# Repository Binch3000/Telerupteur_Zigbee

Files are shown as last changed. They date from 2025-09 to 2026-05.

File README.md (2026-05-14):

# Telerupteur ZigBee FR
Carte de commande pour le contrôle d'un télérupteur avec retour d'état de l'éclairage.

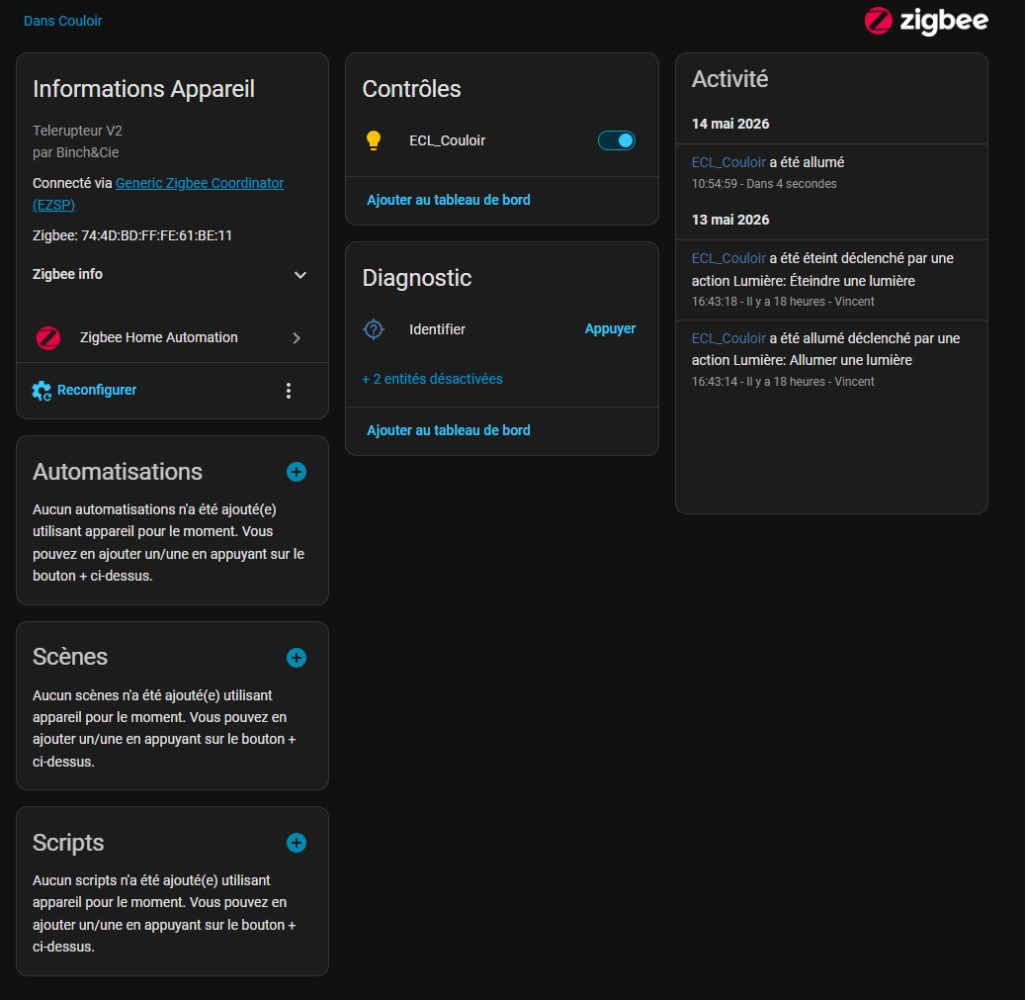
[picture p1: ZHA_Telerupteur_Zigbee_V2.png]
Image ZHA

  
## Pourquoi
Le télérupteur Legrand Drivia 1.991.21 ne remplis pas mon cahier des charges.
J'ai un bon vieux télérupteur à bobine, avec lequel il est possible d'avoir des témoins visuels sur chaque bouton-poussoir. (LED)
L'autre avantage, c'est qu'il se monte comme un bouton-poussoir à l'emplacement voulu.
Il faut également récupérer une alimentation (la même que le télérupteur) ainsi que la puissance de l'éclairage.  

## Liste des composants

Détail dans le ficier ibom.html
- [µP ESP32H2 SuperMini (x1)](https://fr.aliexpress.com/item/1005007235112528.html)
- [Relais HF49FD (x1) HF49FD-005-1H11](https://fr.aliexpress.com/item/1005005163929430.html)

Pour le moment le circuit est maintenu chez moi avec cette boite, dans une GTL. Prendre la version 50-100mm suffit. https://fr.aliexpress.com/item/32624897936.html

## Schéma
- Câblage
- Installation perso

## Évolution :
En fonction des demandes, il sera possible de continuer à développer le projet.
Ceci n'est que quelques idées que j'avais en tête.

- Création d'une boite à imprimer en 3D
- Mise à jour par OTA

## Divers
J'ai la possibilité d'expédier une carte vierge ou même prêt à l'utilisation selon vos besoins.

# ZigBee Remote Switch EN
Control board for controlling a remote switch with lighting status feedback.

Image ZHA

## Why
The Legrand Drivia 1.991.21 remote switch doesn't meet my requirements.
I have a good old-fashioned coil-type remote switch, which allows for visual indicators on each push button (LEDs).
Another advantage is that it can be mounted like a push button in the desired location.
It also requires a power supply (the same as the remote switch) and the power supply for the lighting.

## Component List

Details in the ibom.html file
- [µP ESP32H2 SuperMini (x1)](https://fr.aliexpress.com/item/1005007235112528.html)
- [HF49FD Relay (x1) HF49FD-005-1H11](https://fr.aliexpress.com/item/1005005163929430.html)

For now, the circuit is maintained at home with this box, in a GTL. The 50-100mm version is sufficient. https://fr.aliexpress.com/item/32624897936.html

## Diagram
- Wiring
- Custom Installation

## Evolution:
Depending on demand, it will be possible to continue developing the project.
These are just a few ideas I had in mind.

- Creation of a 3D printed box
- OTA updates

## Miscellaneous
I can ship a blank card or even a ready-to-use one, depending on your needs.

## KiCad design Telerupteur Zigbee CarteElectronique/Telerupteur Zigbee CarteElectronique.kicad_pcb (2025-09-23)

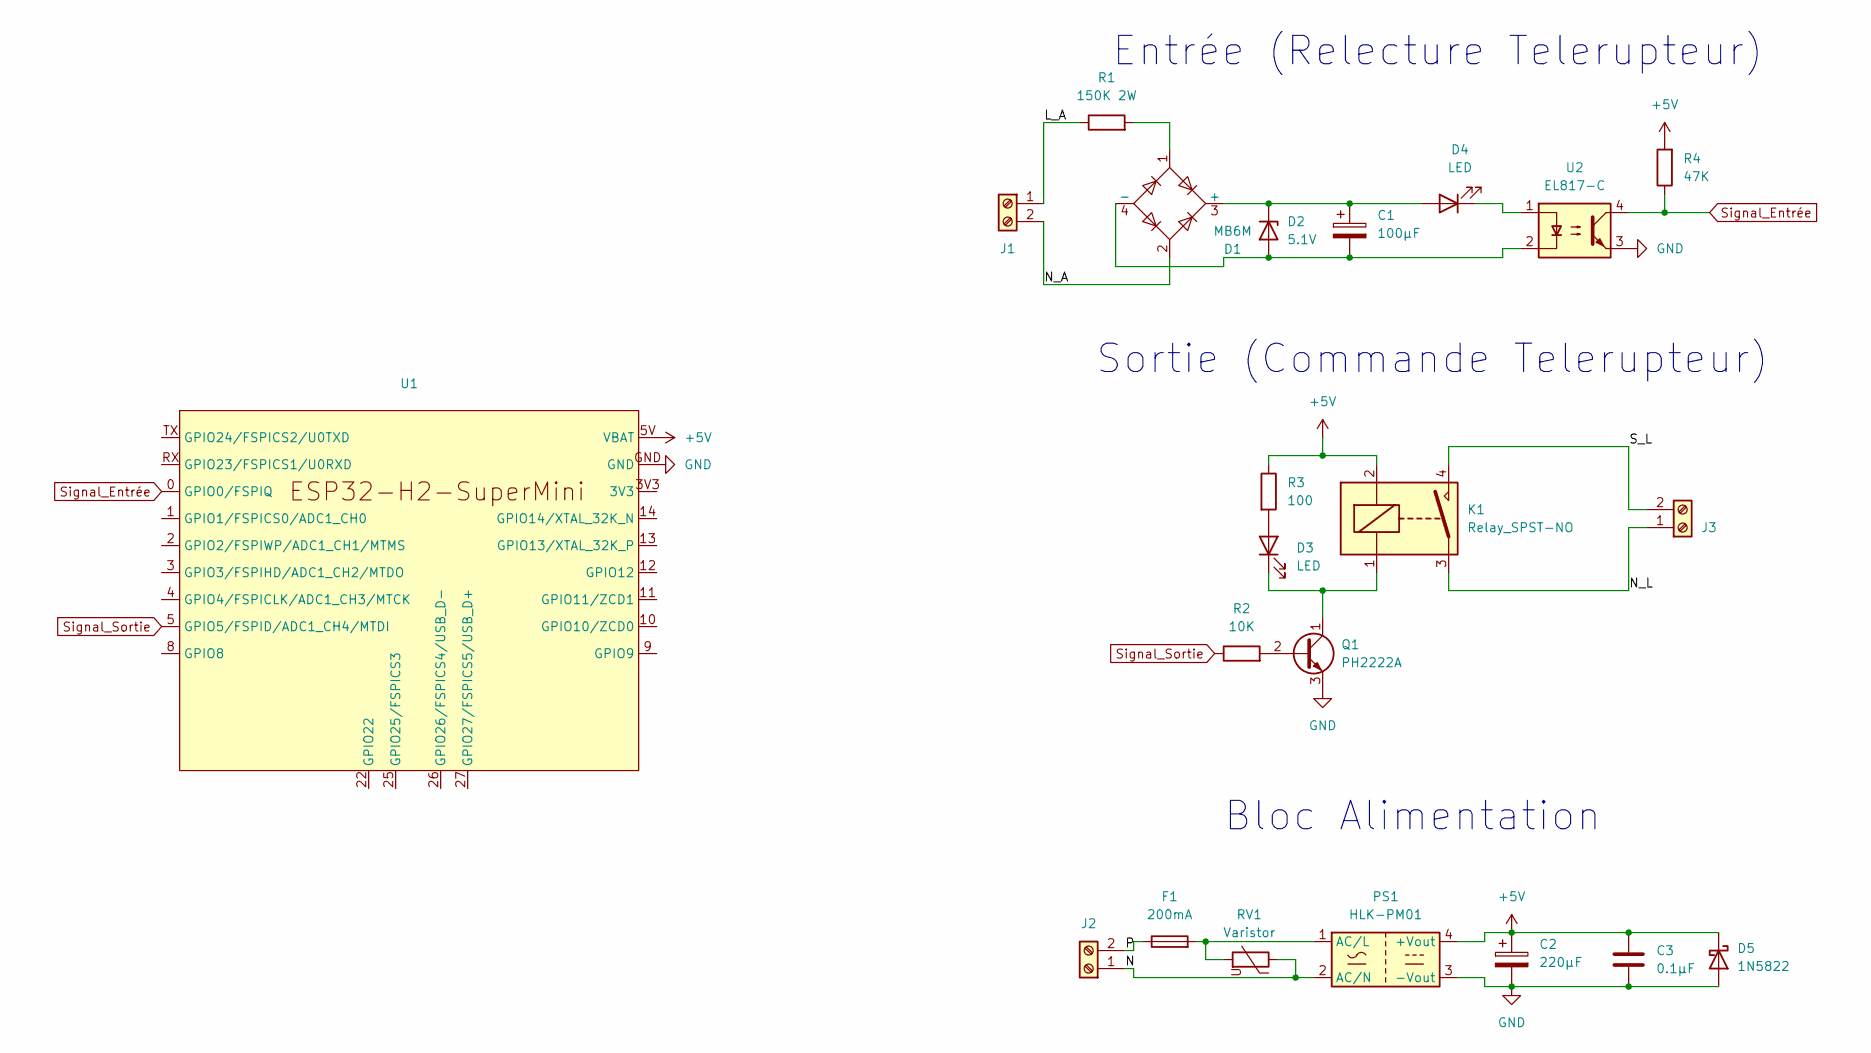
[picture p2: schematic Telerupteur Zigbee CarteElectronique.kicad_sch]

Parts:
C1: 100µF; CP_Radial_D6.3mm_P2.50mm
C2: 220µF; CP_Radial_D6.3mm_P2.50mm
C3: 0.1µF; C_Rect_L10.3mm_W5.0mm_P7.50mm_MKS4
D1: MB6M; Diode_Bridge_DIP-4_W5.08mm_P2.54mm
D2: 5.1V; D_A-405_P7.62mm_Horizontal
D3, D4: LED; LED_D3.0mm
D5: 1N5822; D_T-1_P10.16mm_Horizontal
F1: 200mA; Fuseholder_Cylinder-5x20mm_Schurter_FAB_0031-355x_Horizonta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
J1, J2, J3: Screw_Terminal_01x02; TerminalBlock_Phoenix_PT-1,5-2-5.0-H_1x02_P5.00mm_Horizontal
K1: Relay_SPST-NO; HF49FD
PS1: HLK-PM01; Converter_ACDC_Hi-Link_HLK-PMxx
Q1: PH2222A; TO-92L_Inline_Wide
R1: 150K 2W; R_Axial_DIN0516_L15.5mm_D5.0mm_P20.32mm_Horizontal
R2: 10K; R_Axial_DIN0207_L6.3mm_D2.5mm_P10.16mm_Horizontal
R3: 100; R_Axial_DIN0207_L6.3mm_D2.5mm_P10.16mm_Horizontal
R4: 47K; R_Axial_DIN0207_L6.3mm_D2.5mm_P10.16mm_Horizontal
RV1: Varistor; RV_Disc_D12mm_W3.9mm_P7.5mm
U1: ESP32-H2-SuperMini
U2: EL817-C; DIP-4_W7.62mm

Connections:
+5V: C2.1, C3.1, D5.1 (K), K1.2, PS1.4 (+Vout), R3.1, R4.2, U1.5V (VBAT)
/L_A: J1.1, R1.1
/N: J2.1, PS1.2 (AC/N), RV1.1
/N_A: D1.2, J1.2
/N_L: J3.1, K1.3
/P: F1.1, J2.2
/S_L: J3.2, K1.4
GND: C2.2, C3.2, D5.2 (A), PS1.3 (-Vout), Q1.3 (E), U1.GND, U2.3
unnamed: C1.1, D1.3 (+), D2.1 (K), D4.2 (A)
unnamed: C1.2, D1.4 (-), D2.2 (A), U2.2
unnamed: D1.1, R1.2
unnamed: D3.2 (A), R3.2
unnamed: D3.1 (K), K1.1, Q1.1 (C)
unnamed: D4.1 (K), U2.1
unnamed: F1.2, PS1.1 (AC/L), RV1.2
unnamed: Q1.2 (B), R2.2
Signal_Entrée: R4.1, U1.0 (GPIO0/FSPIQ), U2.4
Signal_Sortie: R2.1, U1.5 (GPIO5/FSPID/ADC1_CH4/MTDI)

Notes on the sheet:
Bloc Alimentation
Entrée (Relecture Telerupteur)
Sortie (Commande Telerupteur)

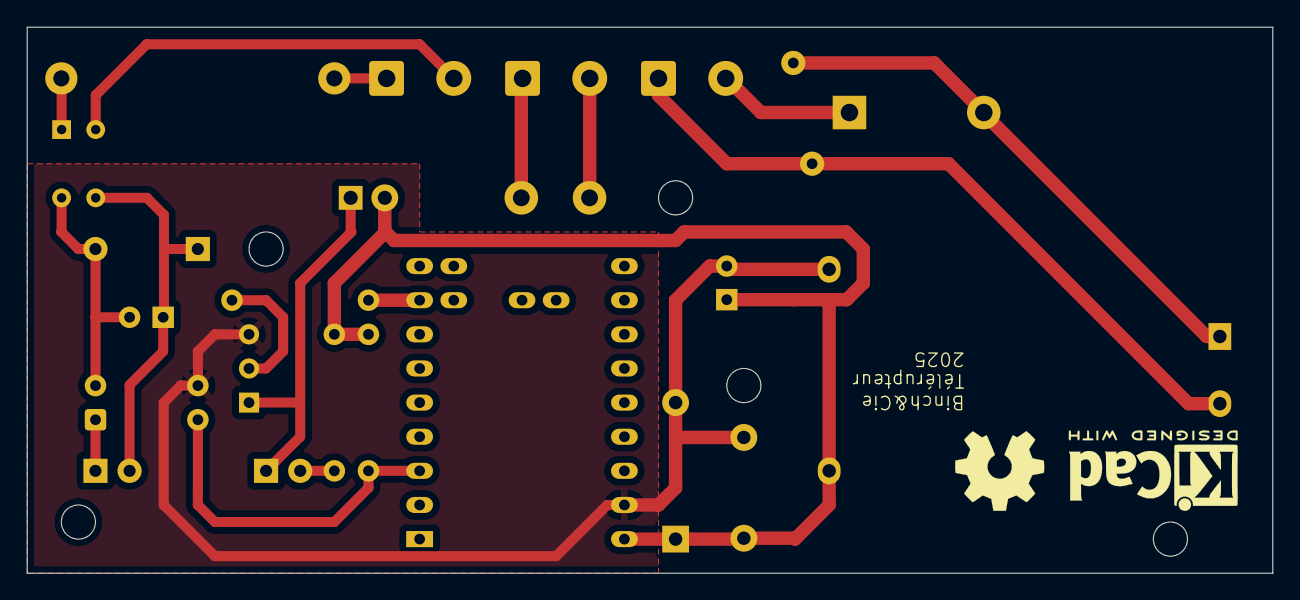
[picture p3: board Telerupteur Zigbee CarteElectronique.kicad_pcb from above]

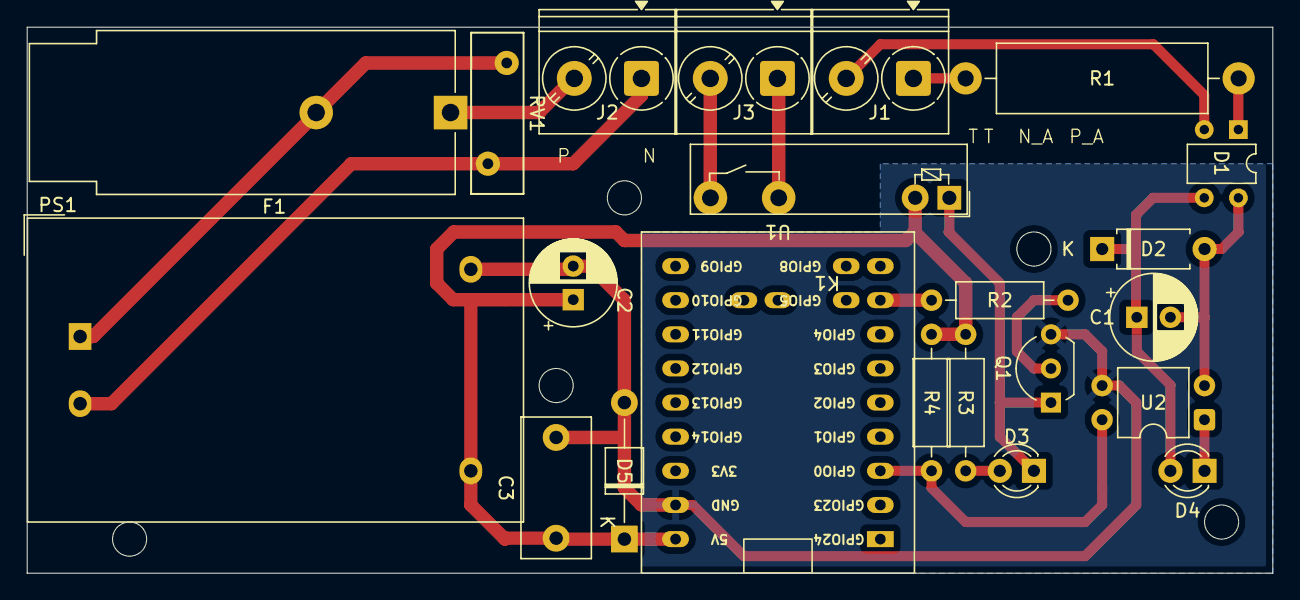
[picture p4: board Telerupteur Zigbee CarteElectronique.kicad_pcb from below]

Board: 2 copper layers, 92.7 x 40.6 mm, 22 parts (22 on the bottom side), 18 nets.

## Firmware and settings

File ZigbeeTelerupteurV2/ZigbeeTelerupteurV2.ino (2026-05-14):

#ifndef ZIGBEE_MODE_ZCZR
#error "Zigbee end device mode is not selected in Tools->Zigbee mode"
#endif

#include "esp_zigbee_core.h"
#include "freertos/FreeRTOS.h"
#include "freertos/task.h"
#include "ha/esp_zigbee_ha_standard.h"

//Attribution des END_POINT Configuration ZigBee
#define END_POINT_1 0x01

//--------Sortie ----------//
//Attribution des pin de sortie
static const byte pinSortie1 = 5;
static const byte pinIdentify = 13;

//Tableau des Pin de sorties
#define NB_PIN_OUT 2
const uint8_t PIN_OUT[NB_PIN_OUT] = { pinSortie1, pinIdentify };            //Attribution des PINs de sorties
const uint8_t END_POINT_OUT_ID[NB_PIN_OUT] = { END_POINT_1, END_POINT_1 };  //Attribution des END_POINT en fonction des PIN_OUT
bool ETAT_LED_OUT[NB_PIN_OUT];


//-------- Entrée ----------//
//Attribution des pin d'entrée
static const byte pinEntre1 = 0;


//Tableau des Pin de entrées
#define NB_PIN_IN 1
const uint8_t PIN_IN[NB_PIN_IN] = { pinEntre1 };             //Attribution des PINs de entrées
const uint8_t END_POINT_IN_ID[NB_PIN_IN] = { END_POINT_1 };  //Attribution des END_POINT en fonction des PIN_INT
bool ETAT_LED_IN[NB_PIN_IN];
bool VAL_COUR_IN = false;  //Valeur Courante Entrante

#define ESP_ZB_ZR_CONFIG() \
  { \
    .esp_zb_role = ESP_ZB_DEVICE_TYPE_ROUTER, \
    .install_code_policy = INSTALLCODE_POLICY_ENABLE, \
    .nwk_cfg = { \
      .zczr_cfg = { \
        .max_children = MAX_CHILDREN, \
      }, \
    }, \
  }

#define ESP_ZB_DEFAULT_RADIO_CONFIG() \
  { .radio_mode = ZB_RADIO_MODE_NATIVE, }

#define ESP_ZB_DEFAULT_HOST_CONFIG() \
  { .host_connection_mode = ZB_HOST_CONNECTION_MODE_NONE, }

/* Zigbee configuration */
#define MAX_CHILDREN 10                                                  /* the max amount of connected devices */
#define INSTALLCODE_POLICY_ENABLE false                                  /* enable the install code policy for security */
#define ESP_ZB_PRIMARY_CHANNEL_MASK ESP_ZB_TRANSCEIVER_ALL_CHANNELS_MASK /* Zigbee primary channel mask use in the example */

/********************* Zigbee functions **************************/

static void Entree_Binaire() {
  for (uint8_t IN = 0; IN < NB_PIN_IN; IN++) {
    // Lire l'état de la broche
    VAL_COUR_IN = !digitalRead(PIN_IN[IN]);  //Lecture etat pin inversée
    // Si l'état a changé
    if (VAL_COUR_IN != ETAT_LED_IN[IN]) {
      ETAT_LED_IN[IN] = VAL_COUR_IN;  // Mettre à jour l'état local
      // Afficher le changement d'état
      if (VAL_COUR_IN) {
        Serial.print("Activation pin : ");
      } else {
        Serial.print("Désactivation pin : ");
      }
      Serial.println(PIN_IN[IN]);
      // Vérification explicite des endpoints
      esp_err_t err = ESP_OK;  // Initialiser la variable d'erreur
      log_v("Updating on/off light state to %u", VAL_COUR_IN);
      /* Update on/off light state */
      esp_zb_lock_acquire(portMAX_DELAY);
      err = esp_zb_zcl_set_attribute_val(END_POINT_IN_ID[IN], ESP_ZB_ZCL_CLUSTER_ID_ON_OFF, ESP_ZB_ZCL_CLUSTER_SERVER_ROLE, ESP_ZB_ZCL_ATTR_ON_OFF_ON_OFF_ID, &VAL_COUR_IN, false);
      esp_zb_lock_release();

      // Vérifier le résultat de l'opération
      if (err != ESP_OK) {
        printf("Erreur lors de l'envoi de la commande pour EndPoint %d : %d\n", END_POINT_IN_ID[IN], err);
      } else {
        printf("Commande envoyée avec succès pour EndPoint %d.\n", END_POINT_IN_ID[IN]);
      }
    }
  }
}

static void bdb_start_top_level_commissioning_cb(uint8_t mode_mask) {
  ESP_ERROR_CHECK(esp_zb_bdb_start_top_level_commissioning(mode_mask));
}

void esp_zb_app_signal_handler(esp_zb_app_signal_t *signal_struct) {
  uint32_t *p_sg_p = signal_struct->p_app_signal;
  esp_err_t err_status = signal_struct->esp_err_status;
  esp_zb_app_signal_type_t sig_type = (esp_zb_app_signal_type_t)*p_sg_p;
  switch (sig_type) {
    case ESP_ZB_ZDO_SIGNAL_SKIP_STARTUP:
      log_i("Zigbee stack initialized");
      esp_zb_bdb_start_top_level_commissioning(ESP_ZB_BDB_MODE_INITIALIZATION);
      break;
    case ESP_ZB_BDB_SIGNAL_DEVICE_FIRST_START:
    case ESP_ZB_BDB_SIGNAL_DEVICE_REBOOT:
      if (err_status == ESP_OK) {
        log_i("Device started up in %s factory-reset mode", esp_zb_bdb_is_factory_new() ? "" : "non");
        //Démmarage de la lecture et de l'envoi des valeurs
        //xTaskCreate(Capteur_valeur_maj, "sensor_update", 2048, NULL, 10, NULL);

        //xTaskCreate(humi_sensor_value_update, "Maj_des_capteurs", 2048, NULL, 10, NULL);  //Envoie des valeurs d'humidité sur le réseau ZigBee
        if (esp_zb_bdb_is_factory_new()) {
          log_i("Start network formation");
          esp_zb_bdb_start_top_level_commissioning(ESP_ZB_BDB_MODE_NETWORK_STEERING);
        } else {
          log_i("Device rebooted");
        }
      } else {
        /* commissioning failed */
        log_w("Failed to initialize Zigbee stack (status: %s)", esp_err_to_name(err_status));
      }
      break;
    case ESP_ZB_BDB_SIGNAL_STEERING:
      if (err_status == ESP_OK) {
        esp_zb_ieee_addr_t extended_pan_id;
        esp_zb_get_extended_pan_id(extended_pan_id);
        log_i("Joined network successfully (Extended PAN ID: %02x:%02x:%02x:%02x:%02x:%02x:%02x:%02x, PAN ID: 0x%04hx, Channel:%d, Short Address: 0x%04hx)",
              extended_pan_id[7], extended_pan_id[6], extended_pan_id[5], extended_pan_id[4], extended_pan_id[3], extended_pan_id[2], extended_pan_id[1],
              extended_pan_id[0], esp_zb_get_pan_id(), esp_zb_get_current_channel(), esp_zb_get_short_address());
      } else {
        log_i("Network steering was not successful (status: %s)", esp_err_to_name(err_status));
        esp_zb_scheduler_alarm((esp_zb_callback_t)bdb_start_top_level_commissioning_cb, ESP_ZB_BDB_MODE_NETWORK_STEERING, 1000);
      }
      break;
    default:
      log_i("ZDO signal: %s (0x%x), status: %s", esp_zb_zdo_signal_to_string(sig_type), sig_type, esp_err_to_name(err_status));
      break;
  }
}

static esp_err_t zb_action_handler(esp_zb_core_action_callback_id_t callback_id, const void *message) {
  esp_err_t ret = ESP_OK;
  switch (callback_id) {
    case ESP_ZB_CORE_SET_ATTR_VALUE_CB_ID: ret = zb_attribute_handler((esp_zb_zcl_set_attr_value_message_t *)message); break;
    default: log_w("Receive Zigbee action(0x%x) callback", callback_id); break;
  }
  return ret;
}

static void esp_zb_task(void *pvParameters) {
  esp_zb_cfg_t zb_nwk_cfg = ESP_ZB_ZR_CONFIG();
  esp_zb_init(&zb_nwk_cfg);
  /* Set default allowed network channels */
  esp_zb_set_channel_mask(ESP_ZB_TRANSCEIVER_ALL_CHANNELS_MASK);

  // ------------------------------ Cluster BASIC ------------------------------
  esp_zb_basic_cluster_cfg_t basic_cluster_cfg = {
    .zcl_version = ESP_ZB_ZCL_BASIC_ZCL_VERSION_DEFAULT_VALUE,
  };
  uint8_t ApplicationVersion = 0x0001;
  uint8_t StackVersion = 0x0002;
  uint8_t HWVersion = 0x0002;
  uint8_t ManufacturerName[] = { 9, 'B', 'i', 'n', 'c', 'h', '&', 'C', 'i', 'e' };
  uint8_t ModelIdentifier[] = { 14, 'T', 'e', 'l', 'e', 'r', 'u', 'p', 't', 'e', 'u', 'r', ' ', 'V', '2' };
  uint8_t DateCode[] = { 8, '2', '0', '2', '6', '0', '5', '0', '7' };

  esp_zb_attribute_list_t *esp_zb_basic_cluster = esp_zb_basic_cluster_create(&basic_cluster_cfg);
  esp_zb_basic_cluster_add_attr(esp_zb_basic_cluster, ESP_ZB_ZCL_ATTR_BASIC_APPLICATION_VERSION_ID, &ApplicationVersion);
  esp_zb_basic_cluster_add_attr(esp_zb_basic_cluster, ESP_ZB_ZCL_ATTR_BASIC_STACK_VERSION_ID, &StackVersion);
  esp_zb_basic_cluster_add_attr(esp_zb_basic_cluster, ESP_ZB_ZCL_ATTR_BASIC_HW_VERSION_ID, &HWVersion);
  esp_zb_basic_cluster_add_attr(esp_zb_basic_cluster, ESP_ZB_ZCL_ATTR_BASIC_MANUFACTURER_NAME_ID, (void *)&ManufacturerName);
  esp_zb_basic_cluster_add_attr(esp_zb_basic_cluster, ESP_ZB_ZCL_ATTR_BASIC_MODEL_IDENTIFIER_ID, (void *)&ModelIdentifier);
  esp_zb_basic_cluster_add_attr(esp_zb_basic_cluster, ESP_ZB_ZCL_ATTR_BASIC_DATE_CODE_ID, (void *)&DateCode);

  // ------------------------------ Cluster IDENTIFY ------------------------------
  esp_zb_identify_cluster_cfg_t identify_cluster_cfg = {};
  esp_zb_attribute_list_t *esp_zb_identify_cluster = esp_zb_identify_cluster_create(&identify_cluster_cfg);

  // ------------------------------ Cluster ON_OFF (Commande Telerupteur) ------------------------------
  esp_zb_on_off_cluster_cfg_t on_off_cluster_cfg = {};
  esp_zb_attribute_list_t *esp_zb_on_off_cluster = esp_zb_on_off_cluster_create(&on_off_cluster_cfg);

  // ------------------------------ Create cluster list ------------------------------
  esp_zb_cluster_list_t *esp_zb_cluster_list_1 = esp_zb_zcl_cluster_list_create();
  esp_zb_cluster_list_add_basic_cluster(esp_zb_cluster_list_1, esp_zb_basic_cluster, ESP_ZB_ZCL_CLUSTER_SERVER_ROLE);
  esp_zb_cluster_list_add_identify_cluster(esp_zb_cluster_list_1, esp_zb_identify_cluster, ESP_ZB_ZCL_CLUSTER_SERVER_ROLE);
  esp_zb_cluster_list_add_on_off_cluster(esp_zb_cluster_list_1, esp_zb_on_off_cluster, ESP_ZB_ZCL_CLUSTER_SERVER_ROLE);

  // ------------------------------ Create endpoint list ------------------------------
  esp_zb_endpoint_config_t endpoint_config_1 = {
    .endpoint = END_POINT_1,
    .app_profile_id = ESP_ZB_AF_HA_PROFILE_ID,
    .app_device_id = ESP_ZB_HA_ON_OFF_LIGHT_DEVICE_ID,  //ESP_ZB_HA_ON_OFF_OUTPUT_DEVICE_ID
  };

  esp_zb_ep_list_t *esp_zb_ep_list = esp_zb_ep_list_create();
  esp_zb_ep_list_add_ep(esp_zb_ep_list, esp_zb_cluster_list_1, endpoint_config_1);

  // ------------------------------ Register Device ------------------------------
  esp_zb_device_register(esp_zb_ep_list);
  esp_zb_core_action_handler_register(zb_action_handler);
  esp_zb_set_primary_network_channel_set(ESP_ZB_PRIMARY_CHANNEL_MASK);

  //Erase NVRAM before creating connection to new Coordinator
  esp_zb_nvram_erase_at_start(false);  //Comment out this line to erase NVRAM data if you are conneting to new Coordinator

  ESP_ERROR_CHECK(esp_zb_start(false));
  esp_zb_main_loop_iteration();
}

/* Handle the light attribute */

static esp_err_t zb_attribute_handler(const esp_zb_zcl_set_attr_value_message_t *message) {
  esp_err_t ret = ESP_OK;

  if (!message) {
    log_e("Empty message");
  }
  if (message->info.status != ESP_ZB_ZCL_STATUS_SUCCESS) {
    log_e("Received message: error status(%d)", message->info.status);
  }

  log_i("Received message: EndPoint(%d), Cluster(0x%x), Attribute(0x%x), Data size(%d)", message->info.dst_endpoint, message->info.cluster, message->attribute.id, message->attribute.data.size);
  // Traitement des messages
  for (uint8_t OUT = 0; OUT < NB_PIN_OUT; OUT++) {
    // Vérifier si le message correspond au endpoint actuel
    if (message->info.dst_endpoint == END_POINT_OUT_ID[OUT]) {
      // Gestion du cluster ON/OFF
      if (message->info.cluster == ESP_ZB_ZCL_CLUSTER_ID_ON_OFF) {
        if (message->attribute.id == ESP_ZB_ZCL_ATTR_ON_OFF_ON_OFF_ID && message->attribute.data.type == ESP_ZB_ZCL_ATTR_TYPE_BOOL) {
          // Si ce n'est pas la broche d'identification
          if (PIN_OUT[OUT] != pinIdentify) {
            // Allumer la LED et attendre
            log_i("Lumière sur ON");
            digitalWrite(PIN_OUT[OUT], HIGH);
            vTaskDelay(pdMS_TO_TICKS(200));
            // Éteindre la LED
            ETAT_LED_OUT[OUT] = false;
            log_i("Lumière sur OFF");
            digitalWrite(PIN_OUT[OUT], LOW);
          }
        }
      }
    }
    // Gestion du cluster IDENTIFY
    else if (message->info.cluster == ESP_ZB_ZCL_CLUSTER_ID_IDENTIFY) {
      if (message->attribute.id == ESP_ZB_ZCL_ATTR_IDENTIFY_IDENTIFY_TIME_ID) {
        // Si la broche correspond à la broche d'identification
        if (PIN_OUT[OUT] == pinIdentify) {
          bool newState = message->attribute.data.value ? *(bool *)message->attribute.data.value : ETAT_LED_OUT[OUT];
          ETAT_LED_OUT[OUT] = newState;
          // Mettre à jour l'état de la LED
          log_i("Light sets to %s", ETAT_LED_OUT[OUT] ? "On" : "Off");
          digitalWrite(PIN_OUT[OUT], HIGH * ETAT_LED_OUT[OUT]);
        }
      }
    }
  }
  return ret;
}
//}

/********************* Arduino functions **************************/

void setup() {
  //Init dialogue
  Serial.begin(115200);
  //Init Sorties
  for (uint8_t INIT_OUT = 0; INIT_OUT < NB_PIN_OUT; INIT_OUT++) {
    pinMode(PIN_OUT[INIT_OUT], OUTPUT);
    digitalWrite(PIN_OUT[INIT_OUT], LOW);
    ETAT_LED_OUT[INIT_OUT] = false;
  }

  //Init Entrées
  for (uint8_t INIT_IN = 0; INIT_IN < NB_PIN_IN; INIT_IN++) {
    pinMode(PIN_IN[INIT_IN], INPUT_PULLUP);
    ETAT_LED_IN[INIT_IN] = false;
  }

  // Init Zigbee
  esp_zb_platform_config_t config = {
    .radio_config = ESP_ZB_DEFAULT_RADIO_CONFIG(),
    .host_config = ESP_ZB_DEFAULT_HOST_CONFIG(),
  };
  ESP_ERROR_CHECK(esp_zb_platform_config(&config));
  // Start Zigbee task
  xTaskCreate(esp_zb_task, "Zigbee_main", 4096, NULL, 5, NULL);
  Serial.println("Démarrage OK");
}

void loop() {
  Entree_Binaire();
}
